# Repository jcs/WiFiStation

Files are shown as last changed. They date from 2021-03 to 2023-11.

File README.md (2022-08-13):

# WiFiStation: A WiFi interface to the MailStation

This project is a set of firmware, tools, and hardware specifications for a
board housing an ESP8266 module which talks to a
[Cidco MailStation](https://jcs.org/2019/05/03/mailstation)
over its parallel port.

WiFiStation acts as a modem with an
[`AT` command interface](https://en.wikipedia.org/wiki/Hayes_command_set)
allowing the MailStation to issue `AT` commands to "dial" to telnet addresses
rather than phone numbers.
This allows the MailStation to use software like
[msTERM](https://github.com/jcs/msTERM)
to connect to BBSes over WiFi rather than its internal modem.

All communication between the WiFiStation and the MailStation is also echoed on
the WiFiStation's USB serial interface, so commands can be sent from a host
computer as well.

For the latest documentation for this project, please see
[my WiFiStation site](https://jcs.org/wifistation).

## Hardware Details

An
~~[MCP23017](http://ww1.microchip.com/downloads/en/DeviceDoc/20001952C.pdf)~~
[MCP23S18](http://ww1.microchip.com/downloads/en/devicedoc/22103a.pdf)
connects to an
[Adafruit Feather HUZZAH ESP8266](https://www.adafruit.com/product/2821)
over ~~I2C~~ SPI and has 12 of its GPIO lines (8 data, 2 input status, and 2
output control) routed to pins on a DB25 connector, which plugs into the
MailStation's printer port.

The full
[BOM can be found here.](https://octopart.com/bom-tool/1wY3fCEg)

## Compiling and Flashing esp8266 Firmware

On macOS:

Install Arduino GUI and esp8266 board info per
[these instructions](https://github.com/esp8266/Arduino#installing-with-boards-manager).

```
$ git clone https://github.com/plerup/makeEspArduino
$ git clone https://github.com/jcs/WiFiStation.git
$ cd WiFiStation/esp8266
WiFiStation/esp8266$ make
- Parsing Arduino configuration files ...
- Finding all involved files for the build ...
[...]
WiFiStation/esp8266$ make upload
=== Using upload port: /dev/tty.usbserial-02331261 @ 115200
esptool.py v3.0
Serial port /dev/tty.usbserial-02331261
Connecting....
Chip is ESP8266EX
Features: WiFi
Crystal is 26MHz
[...]
```

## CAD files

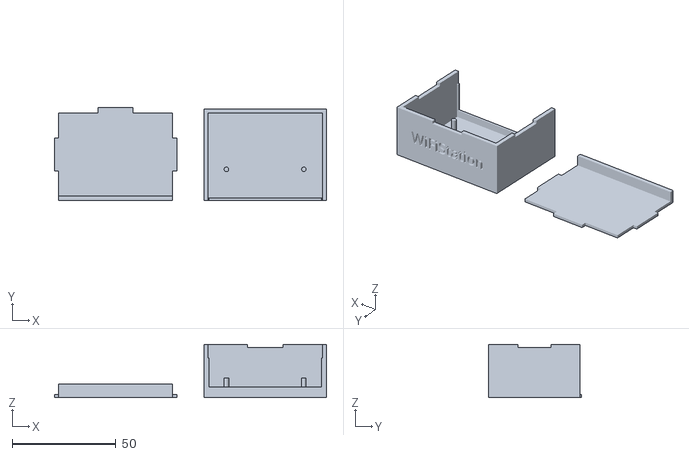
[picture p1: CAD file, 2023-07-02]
enclosure/enclosure-nousb.stl
130.8 x 44.5 x 25.5

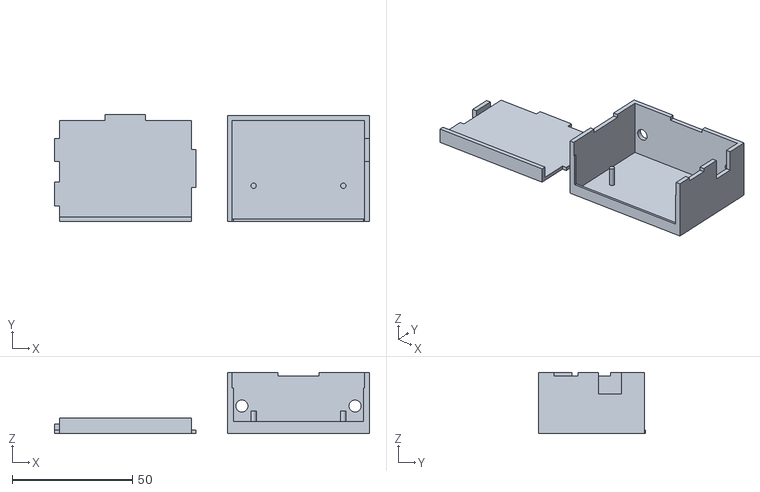
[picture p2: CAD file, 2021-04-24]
enclosure/enclosure.stl
130.8 x 44.5 x 25.5

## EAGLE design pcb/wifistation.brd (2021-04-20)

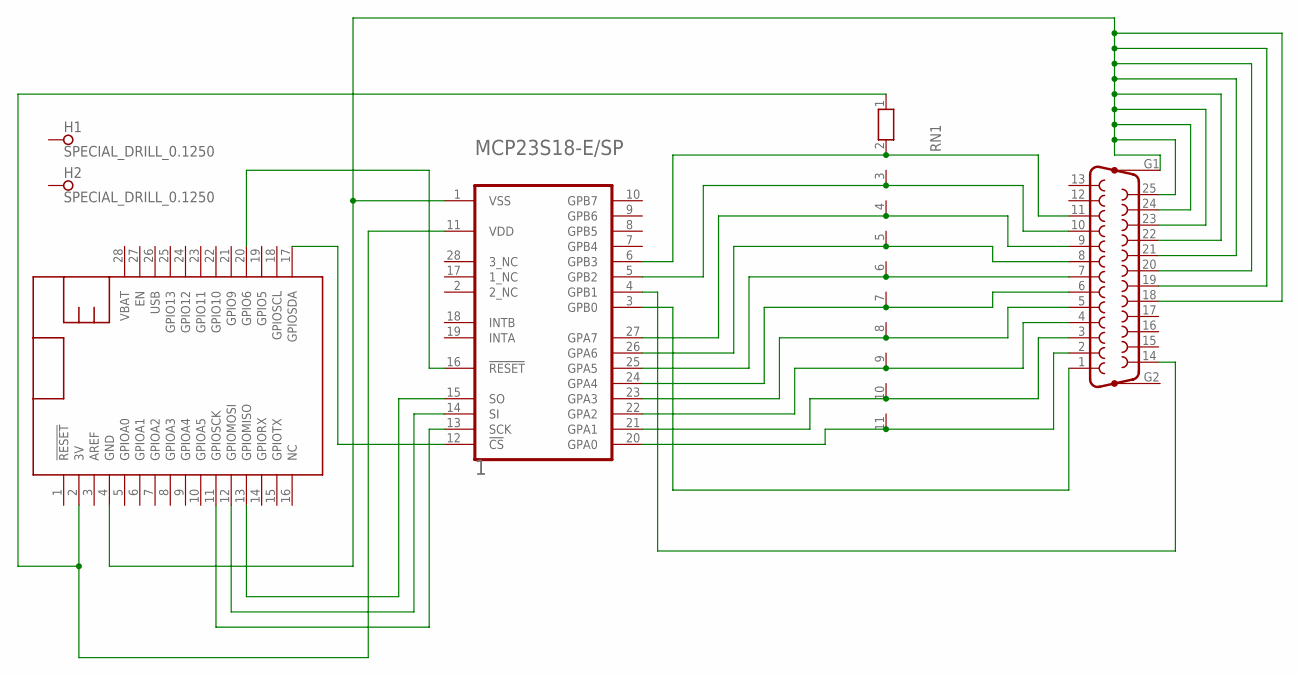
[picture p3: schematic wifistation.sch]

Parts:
1: MICROCHIP_MCP23S18-E-SPMICROCHIP_MCP23S18-E-SP_0_0; MICROCHIP_MCP23S18-E-SP_0
DB25: F25HP
FEATHER: FEATHERWING_NODIM_NOHOLES; FEATHERWING_DIM
H1, H2: SPECIAL_DRILL_0.1250; PAD_0.1250
RN1: RN10; RN-11

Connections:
3V: 1.11 (VDD), FEATHER.2 (3V), RN1.1
ACK: 1.5 (GPB2), DB25.10, RN1.3
BUSY: 1.6 (GPB3), DB25.11, RN1.2
DATA0: 1.20 (GPA0), DB25.2, RN1.11
DATA1: 1.21 (GPA1), DB25.3, RN1.10
DATA2: 1.22 (GPA2), DB25.4, RN1.9
DATA3: 1.23 (GPA3), DB25.5, RN1.8
DATA4: 1.24 (GPA4), DB25.6, RN1.7
DATA5: 1.25 (GPA5), DB25.7, RN1.6
DATA6: 1.26 (GPA6), DB25.8, RN1.5
DATA7: 1.27 (GPA7), DB25.9, RN1.4
LINEFEED: 1.4 (GPB1), DB25.14
unnamed: 1.1 (VSS), DB25.18, DB25.19, DB25.20, DB25.21, DB25.22, DB25.23, DB25.24, DB25.25, DB25.G1, FEATHER.4 (GND)
unnamed: 1.15 (SO), FEATHER.13 (GPIOMISO)
unnamed: 1.16 (!RESET!), FEATHER.20 (GPIO6)
unnamed: 1.14 (SI), FEATHER.12 (GPIOMOSI)
unnamed: 1.13 (SCK), FEATHER.11 (GPIOSCK)
unnamed: 1.12 (!CS!), FEATHER.17 (GPIOSDA)
STROBE: 1.3 (GPB0), DB25.1

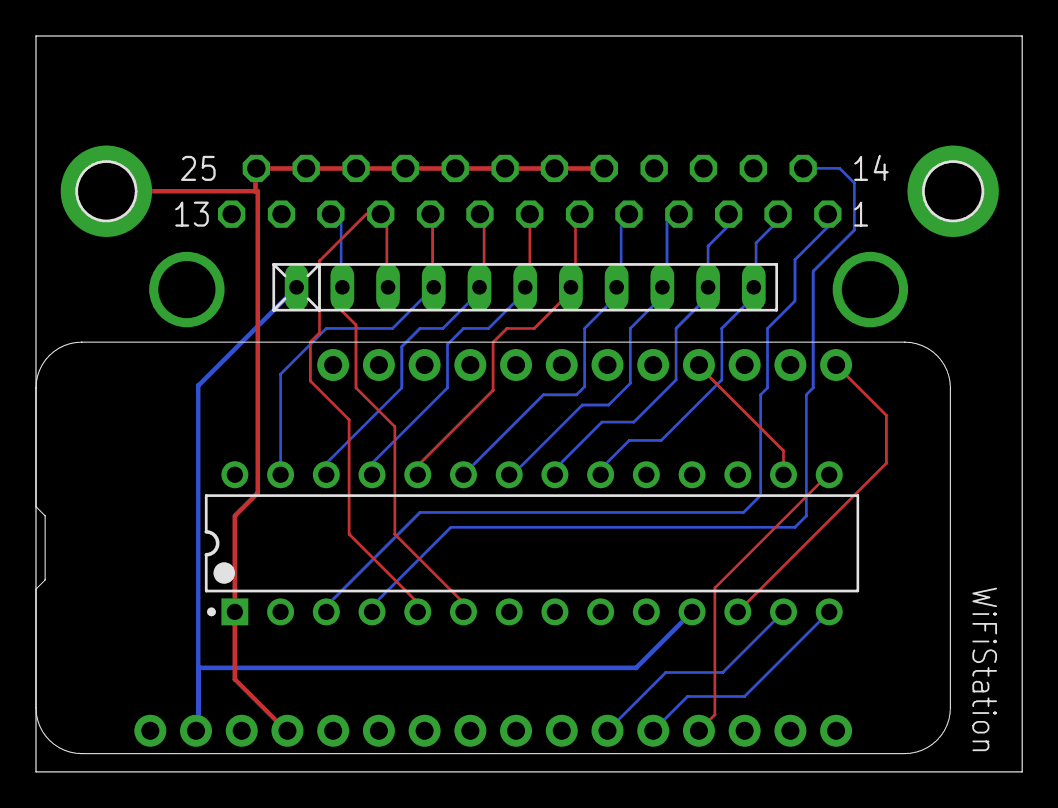
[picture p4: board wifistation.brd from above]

Board: 2 copper layers, 54.8 x 40.9 mm, 6 parts (0 on the bottom side), 19 nets.

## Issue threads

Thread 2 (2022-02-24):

BOM?

hexbus, 2022-02-24:
Greetings, I know you've been out of these for a while.  Can you please put a basic BOM, including any part numbers (if you have them) on the repo?  I'd like to make myself one.  Thanks!

So far, to get started, I've found the following:

- https://www.digikey.com/en/products/detail/microchip-technology/MCP23S18-E-SP/1994655 (MCP23S18)
- https://www.adafruit.com/product/3046 (Assembled Header Huzzah)
- https://www.digikey.com/en/products/detail/te-connectivity-amp-connectors/1-2199298-9/5022045 (28 pin .3 socket)

Still need to locate the proper:

- DB25 connector with proper outline
- 12 pin header (female - pitch?)
- 16 pin header (female - pitch?)
- 4.7k ohm resistor array (is this it?  https://www.digikey.com/en/products/detail/bourns-inc/4611X-101-472LF/3741135 )

Thanks again!  Can't wait to try to get the parts and PCB to try this out.

jcs, 2022-02-25:
Sure, here's an Octopart BOM: https://octopart.com/bom-tool/1wY3fCEg

Closed 2022-08-13.

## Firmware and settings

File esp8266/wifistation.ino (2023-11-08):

/*
 * WiFiStation
 * Copyright (c) 2021 joshua stein <jcs@jcs.org>
 *
 * Permission to use, copy, modify, and distribute this software for any
 * purpose with or without fee is hereby granted, provided that the above
 * copyright notice and this permission notice appear in all copies.
 *
 * THE SOFTWARE IS PROVIDED "AS IS" AND THE AUTHOR DISCLAIMS ALL WARRANTIES
 * WITH REGARD TO THIS SOFTWARE INCLUDING ALL IMPLIED WARRANTIES OF
 * MERCHANTABILITY AND FITNESS. IN NO EVENT SHALL THE AUTHOR BE LIABLE FOR
 * ANY SPECIAL, DIRECT, INDIRECT, OR CONSEQUENTIAL DAMAGES OR ANY DAMAGES
 * WHATSOEVER RESULTING FROM LOSS OF USE, DATA OR PROFITS, WHETHER IN AN
 * ACTION OF CONTRACT, NEGLIGENCE OR OTHER TORTIOUS ACTION, ARISING OUT OF
 * OR IN CONNECTION WITH THE USE OR PERFORMANCE OF THIS SOFTWARE.
 */

/*
 * Useful AT command sets to emulate:
 *
 * USRobotics Courier 56K Business Modem
 * http://web.archive.org/web/20161116174421/http://support.usr.com/support/3453c/3453c-ug/alphabetic.html
 *
 * Xecom XE3314L
 * http://web.archive.org/web/20210816224031/http://static6.arrow.com/aropdfconversion/63e466a4e0c7e004c40f79e4dbe4c1356a3dcef6/xe3314l.pdf
 */

#include "wifistation.h"
#include "MCP23S18.h"

enum {
	STATE_AT,
	STATE_TELNET,
};

static char curcmd[128] = { 0 };
static char lastcmd[128] = { 0 };
static char lasthost[128] = { 0 };
static uint16_t lastport = 0;
static unsigned int curcmdlen = 0;
static unsigned int lastcmdlen = 0;
static uint8_t state = STATE_AT;
static int plusses = 0;
static unsigned long plus_wait = 0;
static bool wifi_ever_connected = false;

void
loop(void)
{
	int b = -1, i;
	long now = millis();

	if (!wifi_ever_connected && WiFi.status() == WL_CONNECTED) {
		rst_info *resetInfo = ESP.getResetInfoPtr();
		syslog.logf(LOG_INFO, "connected, reset from %s (%d)",
		    ESP.getResetReason().c_str(),
		    (resetInfo == nullptr ? 0 : (*resetInfo).reason));
		wifi_ever_connected = true;
	}

	http_process();

	switch (state) {
	case STATE_AT:
		if ((b = ms_read()) != -1) {
			if (!mailstation_alive) {
				/* mailstation can only come alive sending 'a' */
				if (b != 'A' && b != 'a')
					return;
				mailstation_alive = true;
			}
		} else if (Serial.available() && (b = Serial.read()))
			serial_alive = true;
		else
			return;

		/* USR modem mode, ignore input not starting with at or a/ */
		if (curcmdlen == 0 && (b != 'A' && b != 'a')) {
			return;
		} else if (curcmdlen == 1 && b == '/') {
			if (settings->echo)
				output("/\r");
			curcmd[0] = '\0';
			curcmdlen = 0;
			exec_cmd((char *)&lastcmd, lastcmdlen);
			break;
		} else if (curcmdlen == 1 && (b != 'T' && b != 't')) {
			if (settings->echo)
				output("\b \b");
			curcmdlen = 0;
			return;
		}

		switch (b) {
		case '\n':
		case '\r':
			if (b == '\r') {
				/* if sender is using \r\n, ignore the \n */
				now = millis();
				while (millis() - now < 10) {
					int b2 = Serial.peek();
					if (b2 == -1)
						continue;
					else if (b2 == '\n') {
						/* this is a \r\n, ignore \n */
						Serial.read();
						break;
					} else {
						/* some other data */
						break;
					}
				}
			}
			output("\r");
			curcmd[curcmdlen] = '\0';
			exec_cmd((char *)&curcmd, curcmdlen);
			curcmd[0] = '\0';
			curcmdlen = 0;
			break;
		case '\b':
		case 127:
			if (curcmdlen) {
				if (settings->echo)
					output("\b \b");
				curcmdlen--;
			}
			break;
		default:
			curcmd[curcmdlen++] = b;
			output(b);
		}
		break;
	case STATE_TELNET:
		b = -1;

		if (mailstation_alive && (b = ms_read()) != -1) {
			if (b == '\e') {
				/* probably a multi-character command */
				String seq = String((char)b);
				unsigned long t = millis();

				while (millis() - t < 50) {
					if ((b = ms_read()) != -1)
						seq += (char)b;
				}
				telnet_write(seq);
				plusses = 0;
				break;
			}
		} else if (Serial.available() && (b = Serial.read()))
			serial_alive = true;

		if (b == -1 && plus_wait > 0 && (millis() - plus_wait) >= 500) {
			/* received no input within 500ms of a plus */
			if (plusses >= 3) {
				state = STATE_AT;
				if (!settings->quiet) {
					if (settings->verbal)
						output("\r\nOK\r\n");
					else
						output("0\r");
				}
			} else {
				/* cancel, flush any plus signs received */
				for (i = 0; i < plusses; i++)
					telnet_write("+");
			}
			plusses = 0;
			plus_wait = 0;
		} else if (b != -1) {
			if (b == '+') {
				plusses++;
				plus_wait = millis();
				break;
			}

			if (plusses) {
				for (i = 0; i < plusses; i++)
					telnet_write("+");
				plusses = 0;
			}
			plus_wait = 0;
			telnet_write(b);
			break;
		}

		if ((b = telnet_read()) != -1) {
			if (mailstation_alive)
				ms_write(b);
			if (serial_alive)
				Serial.write(b);
			return;
		} else if (!telnet_connected()) {
			if (!settings->quiet) {
				if (settings->verbal)
					output("\r\nNO CARRIER\r\n");
				else
					output("3\r");
			}
			state = STATE_AT;
			break;
		}
		break;
	}
}

void
exec_cmd(char *cmd, size_t len)
{
	unsigned long t;
	char *errstr = NULL;
	char *lcmd, *olcmd;
	char cmd_char;
	uint8_t cmd_num = 0;
	bool did_nl = false;
	bool did_response = false;

	lcmd = olcmd = (char *)malloc(len + 1);
	if (lcmd == NULL) {
		if (settings->verbal)
			outputf("ERROR malloc %zu failed\r\n", len);
		else
			output("4\r");
		return;
	}

#ifdef AT_TRACE
	syslog.logf(LOG_DEBUG, "%s: parsing \"%s\"", __func__, cmd);
#endif

	for (size_t i = 0; i < len; i++)
		lcmd[i] = tolower(cmd[i]);
	lcmd[len] = '\0';

	/* shouldn't be able to get here, but just in case */
	if (len < 2 || lcmd[0] != 'a' || lcmd[1] != 't') {
		errstr = strdup("not an AT command");
		goto error;
	}

	memcpy(&lastcmd, lcmd, len + 1);
	lastcmdlen = len;

	/* strip AT */
	cmd += 2;
	lcmd += 2;
	len -= 2;

parse_cmd:
	if (lcmd[0] == '\0')
		goto done_parsing;

	/* remove command character */
	cmd_char = lcmd[0];
	len--;
	cmd++;
	lcmd++;

	/* find optional single digit after command, defaulting to 0 */
	cmd_num = 0;
	if (cmd[0] >= '0' && cmd[0] <= '9') {
		if (cmd[1] >= '0' && cmd[1] <= '9')
			/* nothing uses more than 1 digit */
			goto error;
		cmd_num = cmd[0] - '0';
		len--;
		cmd++;
		lcmd++;
	}

#ifdef AT_TRACE
	syslog.logf(LOG_DEBUG, "%s: parsing AT %c[%d] args \"%s\"", __func__,
	    cmd_char, cmd_num, lcmd);
#endif

	switch (cmd_char) {
	case 'd': {
		char *host, *ohost, *bookmark;
		uint16_t port;
		int chars;
		int index;

		switch (lcmd[0]) {
		case 't':
			if (len < 2)
				goto error;

			/* ATDT: dial a host */
			host = ohost = (char *)malloc(len);
			if (host == NULL)
				goto error;
			host[0] = '\0';
			if (sscanf(lcmd, "t%[^:]:%u%n", host, &port,
			    &chars) == 2 && chars > 0)
				/* matched host:port */
				;
			else if (sscanf(lcmd, "t%s %u%n", host, &port,
			    &chars) == 2 && chars > 0)
				/* matched host port */
				;
			else if (sscanf(lcmd, "t%[^:]%n", host, &chars) == 1
			    && chars > 0)
				/* host without port */
				port = 23;
			else {
				errstr = strdup("invalid hostname");
				goto error;
			}
			break;
		case 'l':
			if (lcmd[1] == '?') {
				/* ATDL?: show last dialed host */
				if (lasthost[0] == '\0')
					output("\n\r\n");
				else
					outputf("\n%s:%d\r\n", lasthost,
					    lastport);
				did_nl = true;
				len = 0;
				goto done_parsing;
			} else if (lcmd[1] == '\0') {
				/* ATDL: re-dial last dialed host */
				if (lasthost[0] == '\0')
					goto error;
				int len = strlen(lasthost) + 1;
				host = ohost = (char *)malloc(len);
				if (host == NULL)
					goto error;
				strlcpy(host, lasthost, len);
				port = lastport;
			} else
				goto error;
			break;
		case 's':
			/* ATDS: dial a stored host */
			if (sscanf(lcmd, "s%d", &index) != 1)
				goto error;

			if (index < 1 || index > NUM_BOOKMARKS) {
				errstr = strdup("invalid index");
				goto error;
			}

			bookmark = settings->bookmarks[index - 1];

			host = ohost = (char *)malloc(BOOKMARK_SIZE);
			if (host == NULL)
				goto error;

			host[0] = '\0';

			if (sscanf(bookmark, "%[^:]:%hu%n", host, &port,
			    &chars) == 2 && chars > 0)
				/* matched host:port */
				;
			else if (sscanf(bookmark, "%[^:]%n", host, &chars) == 1
			    && chars > 0)
				/* host without port */
				port = 23;
			else {
				errstr = strdup("invalid hostname");
				goto error;
			}
			break;
		default:
			goto error;
		}

		/* no commands can follow */
		len = 0;

		/* skip leading spaces */
		while (host[0] == ' ')
			host++;

		if (host[0] == '\0') {
			errstr = strdup("blank hostname");
			goto error;
		}

		strlcpy(lasthost, host, sizeof(lasthost));
		lastport = port;

		if (!settings->quiet && settings->verbal)
			outputf("\nDIALING %s:%d\r\n", host, port);

		if (telnet_connect(host, port) == 0) {
			if (!settings->quiet) {
				if (settings->verbal)
					outputf("CONNECT %d %s:%d\r\n",
					    settings->baud, host, port);
				else
					output("18\r"); /* 57600 */
			}
			state = STATE_TELNET;
		} else if (!settings->quiet) {
			if (settings->verbal)
				output("\nNO ANSWER\r\n");
			else
				output("8\r");
		}

		did_nl = true;
		free(ohost);
		break;
	}
	case 'e':
		/* ATE/ATE0 or ATE1: disable or enable echo */
		switch (cmd_num) {
		case 0:
			settings->echo = 0;
			break;
		case 1:
			settings->echo = 1;
			break;
		default:
			goto error;
		}
		break;
	case 'h':
		/* ATH/ATH0: hangup */
		switch (cmd_num) {
		case 0:
			telnet_disconnect();
			break;
		default:
			goto error;
		}
		break;
	case 'i':
		/* ATI/ATI#: show information pages */
		switch (cmd_num) {
		case 0: {
			/* ATI0: show settings */
			ip4_addr_t t_addr;
			output("\n");

			outputf("Firmware version:  %s\r\n",
			    WIFISTATION_VERSION);
			outputf("Default baud rate: %d\r\n", settings->baud);
			outputf("Current baud rate: %d\r\n",
			    Serial.baudRate());
			outputf("Default WiFi SSID: %s\r\n",
			    settings->wifi_ssid);
			outputf("Current WiFi SSID: %s\r\n", WiFi.SSID());
			outputf("WiFi connected:    %s\r\n",
			    WiFi.status() == WL_CONNECTED ? "yes" : "no");
			if (WiFi.status() == WL_CONNECTED) {
				outputf("IP address:        %s\r\n",
				    WiFi.localIP().toString().c_str());
				outputf("Gateway IP:        %s\r\n",
				    WiFi.gatewayIP().toString().c_str());
				outputf("DNS server IP:     %s\r\n",
				    WiFi.dnsIP().toString().c_str());
			}
			outputf("MailStation alive: %s\r\n",
			    mailstation_alive ? "yes" : "no");
			outputf("HTTP server:       %s\r\n",
			    settings->http_server ? "yes" : "no");
			outputf("Syslog server:     %s\r\n",
			    settings->syslog_server);
			for (int i = 0; i < NUM_BOOKMARKS; i++) {
				if (settings->bookmarks[i][0] != '\0')
					outputf("ATDS bookmark %d:   %s\r\n",
					    i + 1, settings->bookmarks[i]);
			}
			did_nl = true;
			break;
		}
		default:
			goto error;
		}
		break;
	case 'o':
		/* ATO: go back online after a +++ */
		switch (cmd_num) {
		case 0:
			if (telnet_connected())
				state = STATE_TELNET;
			else
				goto error;
			break;
		default:
			goto error;
		}
		break;
	case 'q':
		/* ATQ/ATQ0 or ATQ1: enable or disable quiet */
		switch (cmd_num) {
		case 0:
			settings->quiet = 0;
			break;
		case 1:
		case 2:
			settings->quiet = 1;
			break;
		default:
			goto error;
		}
		break;
	case 'v':
		/* ATV/ATV0 or ATV1: enable or disable verbal responses */
		switch (cmd_num) {
		case 0:
			settings->verbal = 0;
			break;
		case 1:
			settings->verbal = 1;
			break;
		default:
			goto error;
		}
		break;
	case 'x':
		/* ATX/ATX#: ignore dialtone, certain results (not used) */
		break;
	case 'z':
		/* ATZ/ATZ0: restart */
		switch (cmd_num) {
		case 0:
			if (!settings->quiet) {
				if (settings->verbal)
					output("\nOK\r\n");
				else
					output("0\r");
			}
			ESP.restart();
			/* NOTREACHED */
		default:
			goto error;
		}
		break;
	case '$':
		/* wifi232 commands, all consume the rest of the input string */
		if (strcmp(lcmd, "http=0") == 0) {
			/* AT$HTTP=0: disable http server */
			settings->http_server = 0;
			http_setup();
		} else if (strcmp(lcmd, "http=1") == 0) {
			/* AT$HTTP=1: enable http server */
			settings->http_server = 1;
			http_setup();
		} else if (strcmp(lcmd, "http?") == 0) {
			/* AT$HTTP?: show http server setting */
			outputf("\n%d\r\n", settings->http_server);
		} else if (strcmp(lcmd, "net=0") == 0) {
			/* AT$NET=0: disable telnet setting */
			settings->telnet = 0;
		} else if (strcmp(lcmd, "net=1") == 0) {
			/* AT$NET=1: enable telnet setting */
			settings->telnet = 1;
		} else if (strcmp(lcmd, "net?") == 0) {
			/* AT$NET?: show telnet setting */
			outputf("\n%d\r\n", settings->telnet);
		} else if (strncmp(lcmd, "pass=", 5) == 0) {
			/* AT$PASS=...: store wep/wpa passphrase */
			memset(settings->wifi_pass, 0,
			    sizeof(settings->wifi_pass));
			strncpy(settings->wifi_pass, cmd + 5,
			    sizeof(settings->wifi_pass));

			WiFi.disconnect();
			if (settings->wifi_ssid[0])
				WiFi.begin(settings->wifi_ssid,
				    settings->wifi_pass);
		} else if (strcmp(lcmd, "pass?") == 0) {
			/* AT$PASS?: print wep/wpa passphrase */
			outputf("\n%s\r\n", settings->wifi_pass);
		} else if (strcmp(lcmd, "pins?") == 0) {
			/* AT$PINS?: watch MCP23S18 lines for debugging */
			uint16_t prev = UINT16_MAX;
			int i, done = 0;
			unsigned char b, bit, n, data = 0;
			extern MCP23S18 mcp;

			ms_datadir(INPUT);

			outputf("\n");

			while (!done) {
				ESP.wdtFeed();

				/* watch for ^C */
				if (Serial.available()) {
					switch (b = Serial.read()) {
					case 3:
						/* ^C */
						done = 1;
						break;
					case 'd':
						Serial.printf("data input\r\n");
						ms_datadir(INPUT);
						break;
					case 'D':
						Serial.printf("data output\r\n");
						ms_datadir(OUTPUT);
						break;
					case 'L':
						Serial.printf("linefeed high\r\n");
						mcp.digitalWrite(pLineFeed, HIGH);
						break;
					case 'l':
						Serial.printf("linefeed low\r\n");
						mcp.digitalWrite(pLineFeed, LOW);
						break;
					case 'S':
						Serial.printf("strobe high\r\n");
						mcp.digitalWrite(pStrobe, HIGH);
						break;
					case 's':
						Serial.printf("strobe low\r\n");
						mcp.digitalWrite(pStrobe, LOW);
						break;
					case '0':
					case '1':
					case '2':
					case '3':
					case '4':
					case '5':
					case '6':
					case '7':
						n = (b - '0');
						bit = (data & (1 << n));
						if (bit)
							data &= ~(1 << n);
						else
							data |= (1 << n);
						Serial.printf("turning data%d "
						    "%s (0x%x)\r\n",
						    n, bit ? "off" : " on",
						    data);
						ms_datadir(OUTPUT);
						ms_writedata(data);
						break;
					}
				}

				uint16_t all = ms_status();
				if (all != prev) {
					Serial.print("data: ");
					for (i = 0; i < 8; i++)
						Serial.print((all & (1 << i)) ?
						    '1' : '0');

					Serial.print(" status: ");
					for (; i < 16; i++)
						Serial.print((all & (1 << i)) ?
						    '1' : '0');
					Serial.print("\r\n");
					prev = all;
				}
			}
			ms_datadir(INPUT);
			did_nl = true;
		} else if (strncmp(lcmd, "sb=", 3) == 0) {
			uint32_t baud = 0;
			int chars = 0;

			/* AT$SB=...: set baud rate */
			if (sscanf(lcmd, "sb=%d%n", &baud, &chars) != 1 ||
		    	    chars == 0) {
				if (settings->verbal)
					output("ERROR invalid baud rate\r\n");
				else
					output("4\r");
				break;
			}

			switch (baud) {
			case 110:
			case 300:
			case 1200:
			case 2400:
			case 4800:
			case 9600:
			case 19200:
			case 38400:
			case 57600:
			case 115200:
				settings->baud = baud;
				if (!settings->quiet) {
					if (settings->verbal)
						outputf("\nOK switching to "
						    "%d\r\n", settings->baud);
					else
						output("0\r");
				}
				Serial.flush();
				Serial.begin(settings->baud);
				break;
			default:
				output("ERROR unsupported baud rate\r\n");
				break;
			}
		} else if (strcmp(lcmd, "sb?") == 0) {
			/* AT$SB?: print baud rate */
			outputf("\n%d\r\n", settings->baud);
			did_nl = true;
		} else if (strcmp(lcmd, "scan") == 0) {
			/* AT$SCAN: scan for wifi networks */
			int n = WiFi.scanNetworks();

			/* don't scroll off the screen */
			if (n > 14)
				n = 14;

			output("\n");

			for (int i = 0; i < n; i++) {
				outputf("%02d: %s (chan %d, %ddBm, ",
				    i + 1,
				    WiFi.SSID(i).c_str(),
				    WiFi.channel(i),
				    WiFi.RSSI(i));

				switch (WiFi.encryptionType(i)) {
				case ENC_TYPE_WEP:
					output("WEP");
					break;
				case ENC_TYPE_TKIP:
					output("WPA-PSK");
					break;
				case ENC_TYPE_CCMP:
					output("WPA2-PSK");
					break;
				case ENC_TYPE_NONE:
					output("NONE");
					break;
				case ENC_TYPE_AUTO:
					output("WPA-PSK/WPA2-PSK");
					break;
				default:
					outputf("?(%d)",
					    WiFi.encryptionType(i));
				}

				output(")\r\n");
			}
			did_nl = true;
		} else if (strncmp(lcmd, "ssid=", 5) == 0) {
			/* AT$SSID=...: set wifi ssid */
			memset(settings->wifi_ssid, 0,
			    sizeof(settings->wifi_ssid));
			strncpy(settings->wifi_ssid, cmd + 5,
			    sizeof(settings->wifi_ssid));

			WiFi.disconnect();
			if (settings->wifi_ssid[0])
				WiFi.begin(settings->wifi_ssid,
				    settings->wifi_pass);
		} else if (strcmp(lcmd, "ssid?") == 0) {
			/* AT$SSID?: print wifi ssid */
			outputf("\n%s\r\n", settings->wifi_ssid);
			did_nl = true;
		} else if (strncmp(lcmd, "syslog=", 7) == 0) {
			/* AT$SYSLOG=...: set syslog server */
			memset(settings->syslog_server, 0,
			    sizeof(settings->syslog_server));
			strncpy(settings->syslog_server, cmd + 7,
			    sizeof(settings->syslog_server));
			syslog_setup();
			syslog.logf(LOG_INFO, "syslog server changed to %s",
			    settings->syslog_server);
		} else if (strcmp(lcmd, "syslog?") == 0) {
			/* AT$SYSLOG?: print syslog server */
			outputf("\n%s\r\n", settings->syslog_server);
			did_nl = true;
		} else if (strncmp(lcmd, "tts=", 4) == 0) {
			/* AT$TTS=: set telnet NAWS */
			int w, h, chars;
			if (sscanf(lcmd + 4, "%dx%d%n", &w, &h, &chars) == 2 &&
			    chars > 0) {
				if (w < 1 || w > 255) {
					errstr = strdup("invalid width");
					goto error;
				}
				if (h < 1 || h > 255) {
					errstr = strdup("invalid height");
					goto error;
				}

				settings->telnet_tts_w = w;
				settings->telnet_tts_h = h;
			} else {
				errstr = strdup("must be WxH");
				goto error;
			}
		} else if (strcmp(lcmd, "tts?") == 0) {
			/* AT$TTS?: show telnet NAWS setting */
			outputf("\n%dx%d\r\n", settings->telnet_tts_w,
			    settings->telnet_tts_h);
		} else if (strncmp(lcmd, "tty=", 4) == 0) {
			/* AT$TTY=: set telnet TTYPE */
			memset(settings->telnet_tterm, 0,
			    sizeof(settings->telnet_tterm));
			strncpy(settings->telnet_tterm, cmd + 4,
			    sizeof(settings->telnet_tterm));
		} else if (strcmp(lcmd, "at$tty?") == 0) {
			/* AT$TTY?: show telnet TTYPE setting */
			outputf("%s\r\nOK\r\n", settings->telnet_tterm);
		} else if (strncmp(lcmd, "update?", 7) == 0) {
			/* AT$UPDATE?: show whether an OTA update is available */
			char *url = NULL;
			if (strncmp(lcmd, "update? http", 12) == 0)
				url = lcmd + 8;
			update_process(url, false, false);
			did_response = true;
		} else if (strncmp(lcmd, "update!", 7) == 0) {
			/* AT$UPDATE!: force an OTA update */
			char *url = NULL;
			if (strncmp(lcmd, "update! http", 12) == 0)
				url = lcmd + 8;
			update_process(url, true, true);
			did_response = true;
		} else if (strcmp(lcmd, "update") == 0 ||
		    strncmp(lcmd, "update http", 11) == 0) {
			/* AT$UPDATE: do an OTA update */
			char *url = NULL;
			if (strncmp(lcmd, "update http", 11) == 0)
				url = lcmd + 7;
			update_process(url, true, false);
			did_response = true;
		} else if (strncmp(lcmd, "upload", 6) == 0) {
			/* AT$UPLOAD: mailstation program loader */
			unsigned int bytes = 0;
			unsigned char b;

			if (sscanf(lcmd, "upload %u", &bytes) != 1 ||
			    bytes < 1)
				goto error;

			if (bytes > (MAX_UPLOAD_SIZE - 1)) {
				outputf("\nERROR size cannot be larger than "
				    "%d\r\n", (MAX_UPLOAD_SIZE - 1));
				break;
			}

			/*
			 * Prevent output() from sending data to the
			 * MailStation until we see it on the other side of the
			 * upload.
			 */
			mailstation_alive = false;

			/*
			 * Send low and high bytes of size.
			 *
			 * XXX: Tell the MailStation we're sending one more
			 * byte than we're receiving from sendload so we can
			 * include one trailing null byte because sometimes the
			 * final ack of ms_write will fail to see ack line go
			 * low before WSLoader jumps to the payload.
			 * Figure out why that happens and remove this hack.
			 */
			if (ms_write((bytes + 1) & 0xff) != 0 ||
			    ms_write(((bytes + 1) >> 8) & 0xff) != 0) {
				output("ERROR MailStation failed to receive "
				    "size\r\n");
				break;
			}

			outputf("\nOK send your %d byte%s\r\n", bytes,
			    bytes == 1 ? "" : "s");

			t = millis();
			int written = 0;
			char cksum = 0;
			while (bytes > 0) {
				if (!Serial.available()) {
					if (millis() - t > 5000)
						break;
					yield();
					continue;
				}

				b = Serial.read();
				t = millis();

				if (ms_write(b) != 0)
					break;

				cksum ^= b;
				written++;
				bytes--;

				if (written % 32 == 0)
					output(cksum);
			}

			if (bytes == 0) {
				output(cksum);
				output("\r\nOK good luck\r\n");
				/* XXX: trailing dummy byte, ignore response */
				ms_write(0);
			} else
				outputf("\r\nERROR MailStation failed to "
				    "receive byte with %d byte%s left\r\n",
				    bytes, (bytes == 1 ? "" : "s"));

			did_nl = true;
			break;
		} else
			goto error;

		/* consume all chars */
		len = 0;
		break;
	case '&':
		if (cmd[0] == '\0')
			goto error;

		cmd_char = lcmd[0];
		len--;
		cmd++;
		lcmd++;

		/* find optional single digit after &command, defaulting to 0 */
		cmd_num = 0;
		if (cmd[0] >= '0' && cmd[0] <= '9') {
			if (cmd[1] >= '0' && cmd[1] <= '9')
				/* nothing uses more than 1 digit */
				goto error;
			cmd_num = cmd[0] - '0';
			len--;
			cmd++;
			lcmd++;
		}
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

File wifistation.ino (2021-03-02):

#include "wifistation.h"

enum {
	STATE_IDLE,
	STATE_UPLOAD,
};

static int state = STATE_IDLE;
static char curcmd[128] = { 0 };
static unsigned int curcmdpos = 0;

void
loop(void)
{
	int c;
	char b;

#if 0
	if ((c = msread()) != -1)
		Serial.write(c);
#endif

	if (!Serial.available())
		return;

	b = Serial.read();

	switch (state) {
	case STATE_IDLE:
		if (b == '\r' && Serial.peek() == '\n')
			Serial.read();

		/* USR modem mode, ignore input not starting with 'at' */
		if (curcmdpos == 0 && (b != 'A' && b != 'a')) {
			break;
		} else if (curcmdpos == 1 && (b != 'T' && b != 't')) {
			outputf("\b \b");
			curcmdpos = 0;
			break;
		}

		switch (b) {
		case '\r':
		case '\n':
			output("\r\n");
			curcmd[curcmdpos] = '\0';
			exec_cmd((char *)&curcmd, curcmdpos);
			curcmd[0] = '\0';
			curcmdpos = 0;
			break;
		case '\b':
		case 127:
			if (curcmdpos) {
				output("\b \b");
				curcmdpos--;
			}
			break;
		default:
			curcmd[curcmdpos++] = b;
			output(b);
		}
		break;
	default:
		output("unknown state ");
	}
}

void
exec_cmd(char *cmd, size_t len)
{
	if (len < 2 ||
	    (cmd[0] != 'A' && cmd[0] != 'a') ||
	    (cmd[1] != 'T' && cmd[1] != 't'))
		goto error;

	if (len == 2) {
		output("OK\r\n");
		return;
	}

	switch (cmd[2]) {
	case 'I':
	case 'i':
		if (len > 4)
			goto error;

		switch (len == 3 ? '0' : cmd[3]) {
		case '0':
			/* ATI or ATI0: show settings */
			outputf("Baud rate:         %d\r\n",
			    settings->baud);
			outputf("Default WiFi SSID: %s\r\n",
			    settings->wifi_ssid);
			outputf("Current WiFi SSID: %s\r\n", WiFi.SSID());
			outputf("WiFi Connected:    %s\r\n",
			    WiFi.status() == WL_CONNECTED ? "yes" : "no");
			if (WiFi.status() == WL_CONNECTED) {
				outputf("IP Address:        %s\r\n",
				    WiFi.localIP().toString().c_str());
				outputf("Gateway IP:        %s\r\n",
				    WiFi.gatewayIP().toString().c_str());
				outputf("DNS Server IP:     %s\r\n",
				    WiFi.dnsIP().toString().c_str());
			}
			output("OK\r\n");
			break;
		case '1': {
			/* ATI1: scan for wifi networks */
			int n = WiFi.scanNetworks();

			for (int i = 0; i < n; i++) {
				outputf("%02d: %s (chan %d, %ddBm, ",
				    i + 1,
				    WiFi.SSID(i).c_str(),
				    WiFi.channel(i),
				    WiFi.RSSI(i));

				switch (WiFi.encryptionType(i)) {
				case ENC_TYPE_WEP:
					output("WEP");
					break;
				case ENC_TYPE_TKIP:
					output("WPA-PSK");
					break;
				case ENC_TYPE_CCMP:
					output("WPA2-PSK");
					break;
				case ENC_TYPE_NONE:
					output("NONE");
					break;
				case ENC_TYPE_AUTO:
					output("WPA-PSK/WPA2-PSK");
					break;
				default:
					outputf("?(%d)",
					    WiFi.encryptionType(i));
				}

				output(")\r\n");
			}
			output("OK\r\n");
			break;
		}
		default:
			goto error;
		}
		break;
	case 'Z':
	case 'z':
		output("OK\r\n");
		ESP.reset();
		break;
	case '$':
		/* wifi232 commands */

		/* at$ssid: wifi ssid */
		if (strcasecmp(cmd, "at$ssid?") == 0) {
			outputf("%s\r\nOK\r\n", settings->wifi_ssid);
		} else if (strncasecmp(cmd, "at$ssid=", 8) == 0) {
			memset(settings->wifi_ssid, 0,
			    sizeof(settings->wifi_ssid));
			strncpy(settings->wifi_ssid, cmd + 8,
			    sizeof(settings->wifi_ssid));
			output("OK\r\n");

			WiFi.disconnect();
			if (settings->wifi_ssid[0])
				WiFi.begin(settings->wifi_ssid,
				    settings->wifi_pass);
		}
		/* at$pass: wep/wpa passphrase */
		else if (strcasecmp(cmd, "at$pass?") == 0) {
			outputf("%s\r\nOK\r\n", settings->wifi_pass);
		} else if (strncasecmp(cmd, "at$pass=", 8) == 0) {
			memset(settings->wifi_pass, 0,
			    sizeof(settings->wifi_pass));
			strncpy(settings->wifi_pass, cmd + 8,
			    sizeof(settings->wifi_pass));
			output("OK\r\n");

			WiFi.disconnect();
			if (settings->wifi_ssid[0])
				WiFi.begin(settings->wifi_ssid,
				    settings->wifi_pass);
		} else
			goto error;
		break;
	case '&':
		if (len < 4)
			goto error;

		switch (cmd[3]) {
		case 'W':
		case 'w':
			if (len != 4)
				goto error;

			/* AT&W: save settings */
			if (!EEPROM.commit())
				goto error;

			output("OK\r\n");
			break;
		default:
			goto error;
		}
		break;
	default:
		goto error;
	}

	return;

error:
	output("ERROR\r\n");
}

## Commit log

2021-02-28 Initial working code of sending and receiving to MailStation
    This uses a new LPT interface to the MailStation that uses all 8
    data lines to simplify reading and writing data, rather than using
    the "tribble" style of transfer in the stock firmware.
    This uses an MCP23017 in i2c mode for all of the GPIO, since there
    aren't enough pins on the ESP8266.
2021-02-28 Use 1.7Mhz I2C clock for faster data transfer
    Still kinda slow though :/
2021-03-02 Add AT$UPLOAD and host-side sendload program
    sendload is based off of sendload from my mailstation-tools repo but
    modified to only work on the serial interface and use the new
    AT$UPLOAD command.
    Since the TTL connection is so lacking, we rely on the ESP8266
    echoing bytes back to do flow control and limit throughput, which is
    currently still very limited by the MCP23017<->ESP8266 interface.
    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
2021-03-02 ms_write: Go back to writing each pin individually
    Sending more than a few K of data frequently gets corrupted between
    the ESP8266 and the MailStation (all of the data is echoed between
    ESP8266 and host fine). Rather than writing all of the data pins in
    one shot, go back to writing each pin separately. This is obviously
    slower but it seems to be more reliable.
2021-03-02 Don't output to serial or MailStation until it talks to us
    Once something is received, consider that channel alive and start
    sending output to it. When ms_write() fails, consider the
    MailStation no longer alive.
    [mailstation.cpp, util.cpp, wifistation.ino]
2021-03-02 AT parsing: If errstr is set, print it after "ERROR "
    [wifistation.ino]
2021-03-02 Adafruit_MCP23017: Add license headers
    Fetched from
    https://github.com/adafruit/Adafruit-MCP23017-Arduino-Library/blob/master/license.txt
2021-03-02 sendload: Make serial device a required argument
2021-03-19 MCP23S18: Add new driver modeled after Adafruit_MCP23017
2021-03-19 Switch from the MCP23017 I2C to the MCP23S18 SPI chip
2021-03-19 AT$UPLOAD: Only echo every 32 bytes, and echo an XORed sum
    This speeds up things greatly and reduces a ~16k upload time from
    over 4 minutes to about 9 seconds.
    Using an SPI speed of 10Mhz doesn't seem any faster than 5Mhz, so
    stick with 5Mhz for safety.
    This also avoids feeding the ESP watchdog inside the polling loops
    since we timeout after 500ms anyway and the watchdog won't fire
    inside of that. Not sure if this actually speeds anything up.
    [MCP23S18.cpp, mailstation.cpp, wifistation.ino]
2021-03-19 mailstation: Allow much more time to read/write, don't start alive
    Some CSI operations are very slow on msTERM. Also consider the
    mailstation dead until it sends us an 'A' or 'a' to avoid reading
    garbage from it.
    [mailstation.cpp, util.cpp, wifistation.ino]
2021-04-12 mailstation: GPIO_CS moved to pin 4 in board design, reset in loop
    When the MCP23S18 is not responding, be sure to re-initialize it
    each time since we need to be in the right IOCON mode.
    [mailstation.cpp, util.cpp]
2021-04-12 AT$PINS?: Add l/L/s/S commands to toggle linefeed and strobe pins
    This is useful for manually sending bytes or diagnosing wiring
    issues.
    [wifistation.ino]
2021-04-12 Fix \r vs \n handling, allow \r\n but only act on \n
    Also flush serial output after sending \n
    [util.cpp, wifistation.ino]
2021-04-12 ms_read: If LF/S are both high, assume a reboot and stop talking
    [mailstation.cpp]
2021-04-12 pcb: Add initial version of schematic and board
    [wifistation.brd, wifistation.sch]
2021-04-12 pcb: Add revision B, which fixes the pinout of the DB25 connector
    The pinout of the d-sub part in Eagle was backwards from how I was
    using it :(
    [wifistation.brd, wifistation.sch]
2021-04-12 pcb: Add revision C which grounds the DB25 mounts and pins 18-25
    [wifistation.brd, wifistation.sch]
2021-04-13 ATZ: Use restart instead of reset
    [wifistation.ino]
2021-04-18 Telnet: If MailStation input starts with \e, buffer for a bit
    This is probably a multi-character key input like an arrow key, so
    buffer it and do telnet.print() with all of the input at once so
    hopefully the remote end gets it all at once.
    Fixes sending arrow keys and Page Up/Down to remote systems that
    don't wait very long to read such input.
    [telnet.cpp, wifistation.ino]
2021-04-20 AT parsing: Implement +++ with guard time, ATH, and ATO
    When +++ is received when in STATE_TELNET and no further input is
    received for 500ms, switch to STATE_AT.
    ATH will hangup, ATO will switch back to STATE_TELNET.
    Since the Hayes patent #4,549,302 is now expired, we can implement
    this instead of TIES
    https://en.wikipedia.org/wiki/Time_Independent_Escape_Sequence
2021-04-20 sendload: Fix usage printing
2021-04-20 pcb: Add Revision D of board, much smaller now
    [wifistation.brd]
2021-04-24 enclosure: add final (for now) case design
    [enclosure.stl]
2021-04-24 ms_setup: Only do error LED flash 10 times
    This way the AT interface can still be entered. Also show
    mailstation_alive status in 'ATI' output.
    [mailstation.cpp, wifistation.ino]
2021-04-24 enclosure: make tabs 0.1mm longer for a tighter fit
    [enclosure.stl]
2021-04-25 Update: Add OTA updates with AT$UPDATE
    If there is a new version available, the binary is downloaded, its
    size and MD5 verified, it is flashed, and the system is restarted.
    There is no TLS certificate verification, and MD5 is only used for
    preventing corrupted updates, not as a security mechanism.
    [wifistation.ino]
2021-05-05 telnet_read: Keep reading while telnet object reports available
    There may be bytes to keep reading even after the connection has
    closed.
    Should fix the "Thanks fo" in Tim's video :)
    [telnet.cpp]
2021-05-20 AT$UPLOAD: Add a hack to send a trailing null byte
    For some reason when WSLoader receives the final byte it's expecting
    and then does its 'jp 0x8000', the ack line doesn't go low and
    ms_write() has to timeout waiting for that, which looks like a
    failed upload to sendload.
    This could be worked around by ms_write ignoring the ack on the
    final byte, but every byte counts so if it properly fails to ack, it
    should be an error.
    Until I can figure out why this happens (without adding a delay
    before WSLoader's final jump), send WSLoader one extra null byte so
    we can ignore the result of that ms_write() and still see the proper
    response to the real last byte of what sendload sent.
    [wifistation.ino]
2021-05-20 flashloader: Delay 5 seconds before reading input
    When the CP2104 USB serial chip on the Feather ESP8266 board sees
    the DTR line go low, it causes a reset of the ESP8266. This is
    needed for software (esptool) to be able to put the ESP8266 into its
    bootloader mode.
    Unfortunately this means any serial connection closing causes a
    reboot, which has to reset the MCP23S18, which can cause garbage on
    its GPIO lines going to the DB25 port.
    When sendload is used to upload flashloader, it sends the program
    over and then closes the serial connection, causing the WiFiStation
    to reboot at the same time flashloader is executing and looking for
    input (the size of the program it's about to write to flash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
2021-06-21 esp8266: Use new style for collectHeaders
    https://github.com/esp8266/Arduino/commit/47b8947e724b7441d1ad7c7eefdd6fdf691b19c1
2021-06-21 esp8266: Set BOARD to huzzah rather than defaulting to generic esp8266
2021-09-19 telnet: Improve debugging, fix negotiation
    This lets us connect to sdf.org, also tested with klud.ge and
    bbs.retrobattlestations.com.
    See jcs/msTERM#1
    [telnet.cpp]
2021-09-19 Build: Fix path to binary since board changed
2022-08-13 esp8266: Do telnet tracing through syslog directly, fix negotiation
    [telnet.cpp]
2022-08-13 README: Link to BOM
    closes #2
2023-06-24 esp8266: AT Handling: Add ATQ and ATE, do proper outputting based on those
    With echo enabled, only print \r after accepting a command, and once
    the command wants to start output, it should print the \n. With ATQ
    set (quiet mode), that \n is not printed since the OK or ERROR is
    not printed.
    Also loop through all command input so chained command sequences
    like "ATEQ1" will be parsed as "ATE0" and "ATQ1".
    From WiFiPPP commit b7a04199813fe7dc6a701fe272286300f86641ab
    This is not really needed on WiFiStation but it helps keep code in
    sync.
    [util.cpp, wifistation.ino]
2023-06-24 esp8266: ATV: Support disabling verbal responses (OK/ERROR)
    Reconfigure ATI responses to be more like other modems, moving WiFi
    scanning to ATI5 and general info to ATI4.
    From WiFiPPP commit eb4842b00be378a43f1610fb8875922af0fd4648
    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
    [util.cpp, wifistation.ino]
2023-06-24 esp8266: AT$UPDATE: Allow passing a URL to update from, support non-https
    Also add a 'serve_ota' make target that creates an OTA text file and
    serves it. This should speed up development and allow others to
    update their devices from repos other than mine.
    From WiFiPPP commit d8a0465612ff6c495be3f965de3ca3a4c00cd5bd
2023-06-27 esp8266: AT: Don't print newline after ATH
2023-06-27 esp8266: util: Set default baud to 9600
    This is only used when sending TSPEED but it's worth sending a low
    value in case the remote actually uses it.
2023-07-02 enclosure: Add version with no USB port
    [enclosure-nousb.stl]
2023-07-04 esp8266: update: Make sure body bytes are available
    It looks like the Update class peeks on the socket and gets -1
    because bytes aren't available and interprets that as 0xff, which
    fails the first-byte-0xE9 test.
2023-11-08 esp8266: Fix sscanf match for at$upload
    [wifistation.ino]
2024-02-26 pcb: Add gerber files I used for the last batch of PCBs
    [copper_bottom.gbr, copper_top.gbr, gerber_job.gbrjob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]
